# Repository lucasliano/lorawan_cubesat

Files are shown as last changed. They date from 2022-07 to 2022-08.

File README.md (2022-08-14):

<!--
*** To avoid retyping too much info. Do a search and replace for the following:
*** lorawan_cubesat, LoRaWAN Gateway for cubesat mission, project_description
-->

<!-- PROJECT LOGO -->
<br />
<p align="center">
  <a href="https://github.com/lucasliano/lorawan_cubesat">
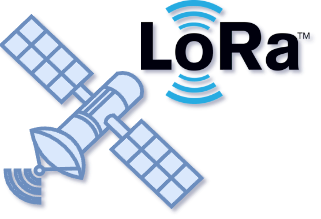
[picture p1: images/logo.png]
    
  </a>

  <h2 align="center">LoRaWAN Gateway:</h3>
  <h3 align="center">Design Criteria for Cubesat Mission</h2>

  <p align="center">
    Cubesat submodule development for a LoRaWAN Gateway capable of operating in harsh environments.
    This project has available not only the design files, but also a report describing the design criteria used. 
    <br />
    <a href="https://github.com/lucasliano/lorawan_cubesat/blob/master/report_spanish.pdf"><strong>Explore the docs »</strong></a>
    <br />
    <br />
    <a href="https://github.com/lucasliano/lorawan_cubesat/tree/master/HW">View Demo</a>
    ·
    <a href="https://github.com/lucasliano/lorawan_cubesat/issues">Report Bug</a>
    ·
    <a href="https://github.com/lucasliano/lorawan_cubesat/issues">Request Feature</a>
  </p>
</p>

<!-- TABLE OF CONTENTS -->
<details open="open">
  <summary><h2 style="display: inline-block">Table of Contents</h2></summary>
  <ol>
    <li><a href="#about-the-project">About The Project</a></li>
    <li><a href="#getting-started">Getting Started</a></li>
    <li><a href="#contributing">Contributing</a></li>
    <li><a href="#license">License</a></li>
    <li><a href="#contact">Contact</a></li>
    <li><a href="#acknowledgements">Acknowledgements</a></li>
  </ol>
</details>

<!-- ABOUT THE PROJECT -->
## About The Project

The project was presented as the final assignament of the subject _Introduction to the design of Printed Circuit Boards_, in the _Electronics Engineering_ carrear at the _Universidad Tecnológica Nacional_ located in Buenos Aires, Argentina.

The main goal of the project was to described the design criteria used in the implementation of the layout, while desiging for manufacturing. As the project was develop in less than 2 month, which you can verify looking at the history of this repo, the scope was modified.

I'm still learning about these topics. If you find something wrong in the design, please let me know. I will be grateful at any feedback received.

In this project you will find the `Altium Designer` project files:

<p align="center">
  <a href="https://github.com/lucasliano/lorawan_cubesat/tree/master/HW">
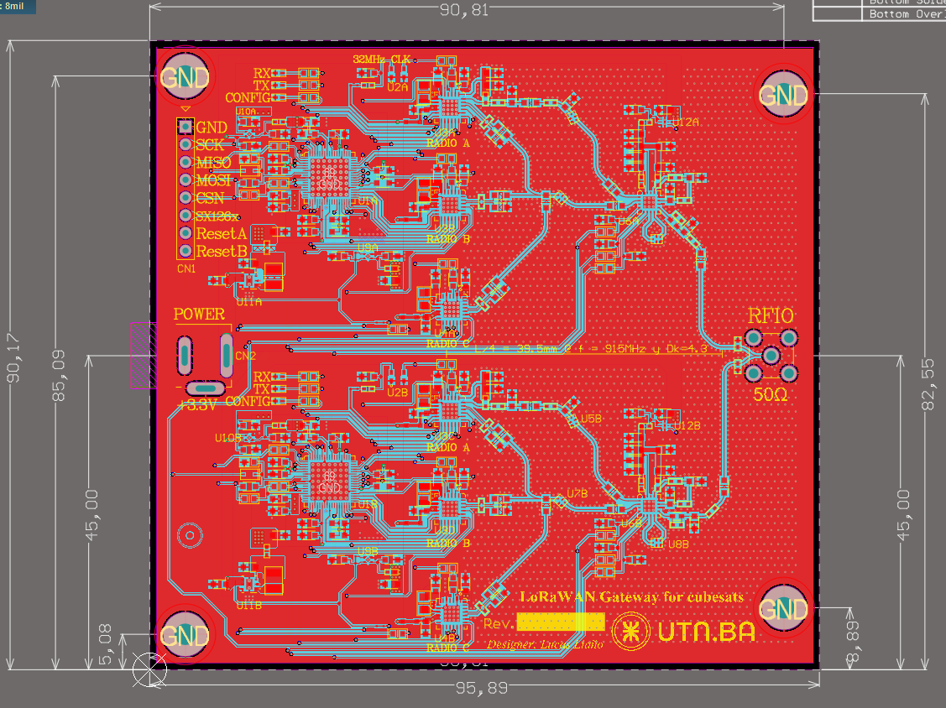
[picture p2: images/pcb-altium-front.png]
  
  </a>
  <p align="center" style="font-size:0.75em;">Figure 1: Altium Designer view for the top leyer of the PCB layout.</p>
</p>

As well as a report containing all the details of the development. Unfortunately, this report is only available in spanish. If you are an english-speaker, please contact me if you have any concerns. 

<p align="center">
  <a href="https://github.com/lucasliano/lorawan_cubesat/blob/master/report_spanish.pdf">
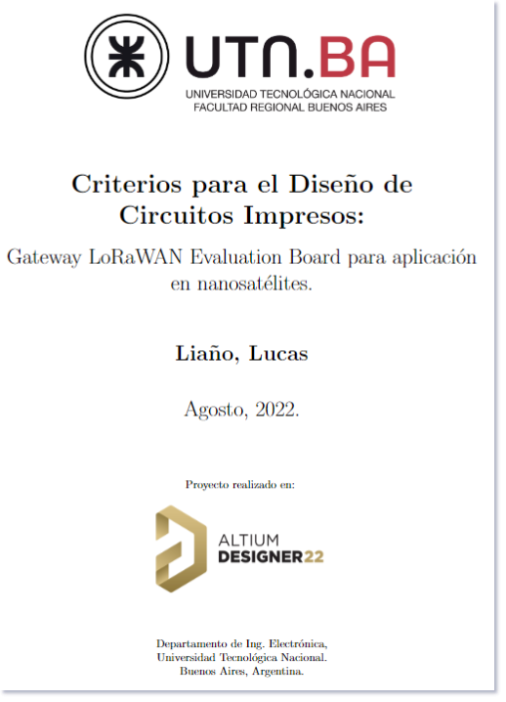
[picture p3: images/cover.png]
  
  </a>
  <p align="center" style="font-size:0.75em;">Figure 2: Report cover.</p>
</p>

<!-- GETTING STARTED -->
## Getting Started

This project was develop using Altium Designer 22. The project folder is '_HW/lorawan_gateway_'.

Cloning the repo will be enough to explore the design files. You will need an Altium Designer license

   ```sh
   git clone https://github.com/lucasliano/lorawan_cubesat.git
   ```

<!-- CONTRIBUTING -->
## Contributing

Contributions are what make the open source community such an amazing place to be learn, inspire, and create. Any contributions you make are **greatly appreciated**.

1. Fork the Project
2. Create your Feature Branch (`git checkout -b feature/AmazingFeature`)
3. Commit your Changes (`git commit -m 'Add some AmazingFeature'`)
4. Push to the Branch (`git push origin feature/AmazingFeature`)
5. Open a Pull Request

See the [open issues](https://github.com/lucasliano/lorawan_cubesat/issues) for a list of proposed features (and known issues).

<!-- LICENSE -->
## License

Distributed under the MIT License. See `LICENSE` for more information.

However, I would appreciate if you tell me in case find this information helpful (or not).

<!-- CONTACT -->
## Contact

[Lucas Liaño](https://www.linkedin.com/in/lucas-lia%C3%B1o/) - lliano@frba.utn.edu.ar

Project Link: [https://github.com/lucasliano/lorawan_cubesat](https://github.com/lucasliano/lorawan_cubesat)

<!-- ACKNOWLEDGEMENTS -->
## Acknowledgements

* [Semtech SX1302 Reference Design files](https://www.semtech.com/products/wireless-rf/lora-core/sx1302cssxxxgw1)

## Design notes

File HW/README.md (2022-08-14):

# This folder contains all the hardware related files.

The following images are a preview of the final PCB, and its panel. 

## Design files

<p align="center">
  
  <p align="center" style="font-size:1em;">Figure 1: Altium Designer view for the top leyer of the PCB layout.</p>
</p>

<p align="center">
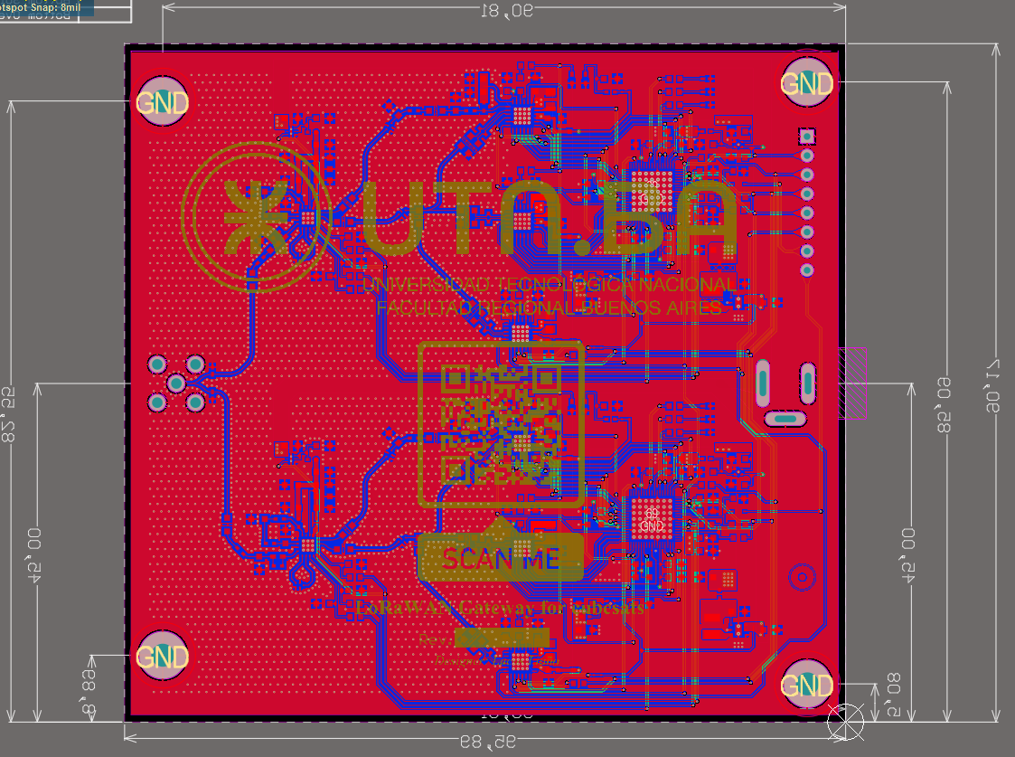
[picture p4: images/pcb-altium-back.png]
  
  <p align="center" style="font-size:1em;">Figure 2: Altium Designer view for the bottom leyer of the PCB layout.</p>
</p>

## 3D Renders

<p align="center">
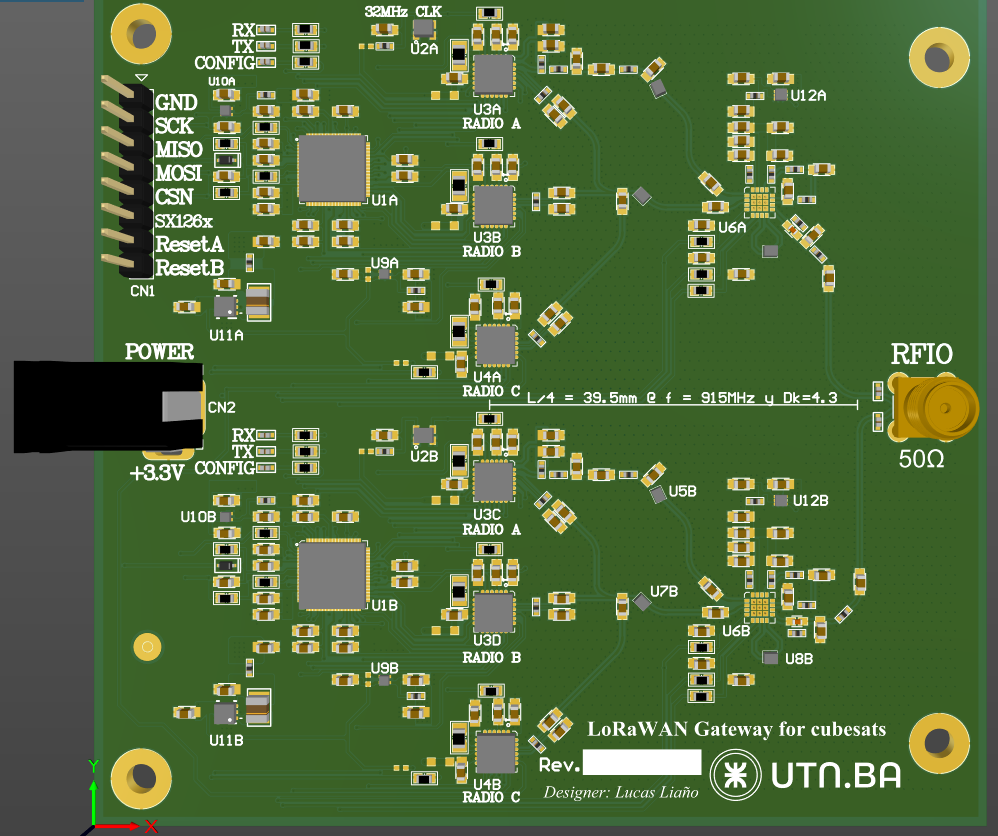
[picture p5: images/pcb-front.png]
  
  <p align="center" style="font-size:1em;">Figure 3: 3D render of the top view.</p>
</p>

<p align="center">
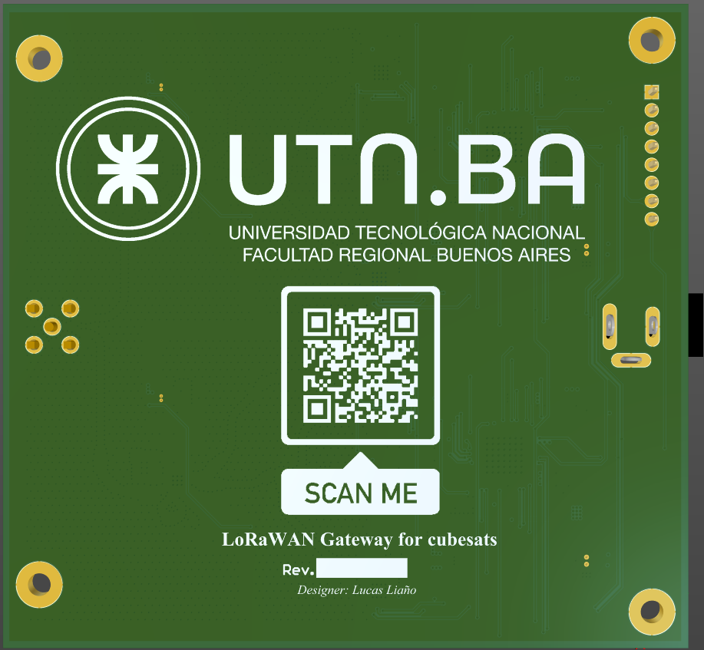
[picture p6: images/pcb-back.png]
  
  <p align="center" style="font-size:1em;">Figure 4: 3D render of the bottom view.</p>
</p>

## Panel 3D render

<p align="center">
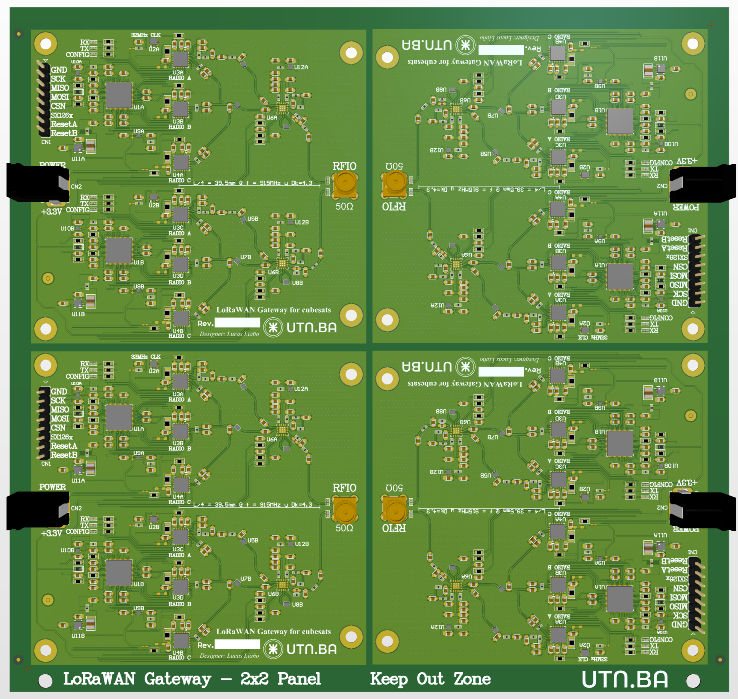
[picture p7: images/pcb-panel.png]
  
  <p align="center" style="font-size:1em;">Figure 5: 3D render of the fianl panel.</p>
</p>

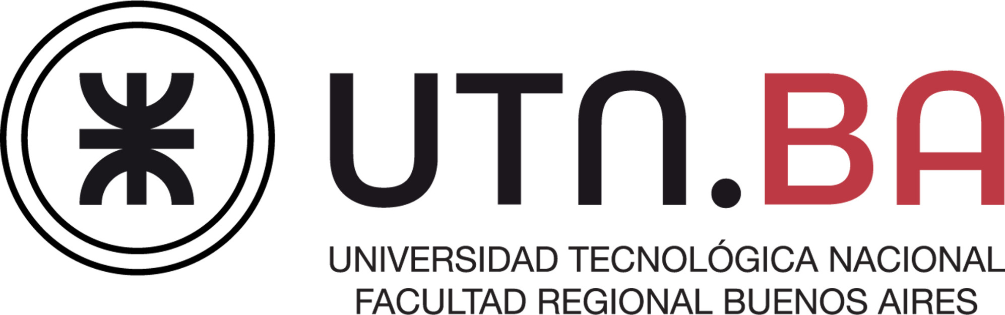
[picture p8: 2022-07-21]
images/utn.jpg

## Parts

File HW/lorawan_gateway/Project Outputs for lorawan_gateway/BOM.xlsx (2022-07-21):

Designator | MPN | Comment | Description | Footprint | Quantity
C1A, C1B, C2A, C2B, C4A, C4B, C5A, C5B, C6A, C6B, C7A, C7B, C9A, C9B, C11A, C11B, C13A, C13B, C26A, C26B, C26C, C26D, C32A, C32B, C50A, C50B, C53A, C53B, C59A, C59B, C60A, C60B | C1206C104K4HACAUTO | 100nF 16V X8R | Capacitor | C_0603 | 32
C3A, C3B, C8A, C8B, C10A, C10B, C12A, C12B, C23A, C23B, C23C, C23D, C29A, C29B | CGA4J3X8R1C105K125AB | 1uF 16V X8R | Capacitor | C_0603 | 14
C14A, C14B | GCM188R91H102KA37D | 100nF 50V X8R | Capacitor | C_0603 | 2
C15A, C15B | GCM188R91H472KA37D | 47nF 50V X8R | Capacitor | C_0603 | 2
C16A, C16B | 0603J0500470GAT | 47pF 50V C0G | Capacitor | C_0603 | 2
C17A, C17B | 06035A390FAT2A | 39pF 50V C0G | Capacitor | C_0603 | 2
C18A, C18B, C38A, C38B | GRM0335C1H100FA01D | 10pF 50V C0G | Capacitor | C_0603 | 4
C19A, C19B | GRM0335C1H2R7WA01D | 2.7pF 50V C0G | Capacitor | C_0603 | 2
C20A, C20B | ML03512R1BAT2A | 2.1pF 50V C0G | Capacitor | C_0603 | 2
C21A, C21B, C21C, C21D, C27A, C27B | C0603X100J8HACAUTO | 10pF 10V X8R | Capacitor | C_0603 | 6
C22A, C22B, C22C, C22D, C24A, C24B, C24C, C24D | GJM0335C1H3R6WB01 | 3.6pF 50V C0G | Capacitor | C_0603 | 8
C25A, C25B, C25C, C25D, C31A, C31B | VJ0603H472JXXAC | 470nF 25V X8R | Capacitor | C_0603 | 6
C28A, C28B, C39A, C39B | GJM0335C1H2R4WB01 | 2.4pF 50V C0G | Capacitor | C_0603 | 4
C30A, C30B, C44A, C44B | GJM0335C1H1R8WB01 | 1.8pF 50V C0G | Capacitor | C_0603 | 4
C33A, C33B, C49A, C49B, C55A, C55B, C57A, C57B | CGA5L3X8R1C475M160AB | 4.7uF 16V X8R | Capacitor | C_0603 | 8
C34A, C34B | C0603C103J3HAC7867 | 10nF 25V X8R | Capacitor | C_0603 | 2
C35A, C35B | C0603C102J1HACAUTO | 1nF 100V X8R | Capacitor | C_0603 | 2
C36A, C36B | GJM1555C1H330GB01 | 33pF 50V C0G | Capacitor | C_0603 | 2
C37A, C37B | GRM1555C2A121GE01 | 120pF 100V C0G | Capacitor | C_0603 | 2
C40A, C40B, C41A, C41B, C43A, C43B, C45A, C45B, C46A, C46B, C47A, C47B | 0603J0500560KCT | 56pF 50V C0G | Capacitor | C_0603 | 12
C42A, C42B | GJM0335C1H2R1BB01 | 2.1pF 50V C0G | Capacitor | C_0402 | 2
C48A, C48B | C2012X7R1A106K125AC | 10uF 10V X7R | Capacitor | C_0603 | 2
C51A, C51B, C52A, C52B, C54A, C54B, C56A, C56B | C0603C105K8RAC7867 | 1uF 10V X7R | Capacitor | C_0603 | 8
C58A, C58B | CGA6P3X8R1C106M250AB | 10uF 16V X8R | Capacitor | C_0603 | 2
CN1 | 2011-1X08G00SB | Generic 1x8 Connector | Connector Generic 8 Vias | Header_M_1x8_0.1" | 1
CN2 | PJ-002B | Barrel Power Connector | CONN PWR JACK 2.5X5.5MM SOLDER | PJ002B | 1
D1A, D1B | BAT54XV2T1G | BAT54XV2T1G | DIODE SCHOTTKY 30V 200MA SOD523 | SOD-523 | 2
D2A, D2B, D3A, D3B, D4A, D4B | APHHS1005SURCK | APHHS1005SURCK | LED | D_0402 | 6
D5A, D5B | LXES15AAA1-153 | LXES15AAA1-153 | LXES Series - ESD Protection Device - Ultra Low Capacitance | D_0402 | 2
F1A, F1B, F2A, F2B, F3A, F3B, F4A, F4B, F5A, F5B | BLM15PG100SN1D | BLM15PG100SN1D | Ferrite bead 10 ohm 1A | L_0402 | 10
J1 | 1053374-1 | SMA RF Connector | SMA 50 Ohm military grade THT connector | SMA THT connector | 1
L1A, L1B | LQW15AN47NJ00D | LQW15AN47NJ00D | Inductor | L_0402 | 2
L2A, L2B | LQW15AN2N5C00D | LQW15AN2N5C00D | Inductor | L_0402 | 2
L3A, L3B | LQW15AN4N7C00 | LQW15AN4N7C00 | Inductor | L_0402 | 2
L4A, L4B, L4C, L4D | LQW15AN12NH00D | 12nH 500mA | Inductor | L_0402 | 4
L5A, L5B, L5C, L5D, L7A, L7B | MLZ2012M150WT000 | 15uH 250mA | FIXED IND 15UH 250MA 950MOHM SMD | 0805[2012] | 6
L6A, L6B | LQW15AN15NH00D | LQW15AN15NH00D | Inductor | L_0402 | 2
L8A, L8B | LQW15AN6N8G80D | 6.8nH 1.45A | Inductor | L_0402 | 2
L9A, L9B | LQG15WZ2N7C02D | 2.7nH 900mA | Inductor | L_0402 | 2
L10A, L10B | LQW15AN7N5J00D | 7.5nH 570mA | Inductor | L_0402 | 2
L11A, L11B | LQP15MN1N2B02 | 1.2nH 390mA | Inductor | L_0402 | 2
L12A, L12B | LQW15AN4N7C00 | 4.7nH 750mA | Inductor | L_0402 | 2
L13A, L13B | LQG15HN3N3S02 | 3.3nH 800mA | Inductor | L_0402 | 2
L14A, L14B | LQM2HPN2R2MJ0L | 2.2uH 1A | FIXED IND 2.2UH 1A 150 MOHM | L_1008 | 2
R1A, R1B, R12A, R12B | RMCF0201JT100R | 100R 5% 1/20W | Resistor | 0603[1608] | 4
R2A, R2B | Vishay | 10R 5% 1/20W | Resistor | 0603[1608] | 2
R3A, R3B, R7A, R7B | M55342K11B47K0MT1V | 47k 5% 1/20W | Resistor | 0603[1608] | 4
R4A, R4B, R5A, R5B, R6A, R6B | ERJ-H3GJ681V | 680R 5% 1/8W | Resistor | 0603[1608] | 6
R10A, R10B, R10C, R10D, R11A, R11B | ERJ-1GNJ221C | 220R 5% 1/20W | Resistor | 0603[1608] | 6
R13A, R13B, R14A, R14B, R15A, R15B | RMCF0201JT1K00 | 1k 5% 1/20W | Resistor | 0603[1608] | 6
U1A, U1B | SX1302 | SX1302IMLTRT | LoRa Core™ Digital Baseband Chip for LoRaWAN network gateways | vqfn68_7x7mm | 2
U2A, U2B | NT2016SA 32MHz END4263A | 32MHz Clipped Sinewave | 32MHz TCXO - Clipped Sinewave Output | TCXO 2.0x1.6mm | 2
U3A, U3B, U3C, U3D | SX1250IMLTRT | SX1250 | SX1250 - Ultra low power RF Front-End | vqfn24_4x4mm | 4
U4A, U4B | SX1261IMLTRT | SX1261/2 | SX1261/2 - Ultra low power RF transceiver | vqfn24_4x4mm | 2
U5A, U5B, U7A, U7B, U8A, U8B | B39921B4344P810 | SAW Filter RF360 | SAW Filter RF360 | QCS5P_1.4x1.1mm | 6
U6A, U6B | SKY66423-11 | SKY66423-11 | SKY66423-11 - 860 to 930MHz Front-End Module | SKY66420_16P_3x3mm | 2
U9A, U9B | NCP114AMX330TBG | LDO 3.3V | LDO IC Positive Fixed 1 Output 300mA 4-UDFN (1.0x1.0) | UDFN4_1x1mm | 2
U10A, U10B | NCP103AMX300TCG | LDO 3V3 | LDO IC Positive Fixed 1 Output 150mA 4-UDFN | UDFN4_1x1mm | 2
U11A, U11B | TPS62242DRVT | Switching Regulator 1.2V | Switching Regulator IC Positive Fixed 1.2V 1 Output 300mA 6-WDFN | WSON-6 | 2
U12A, U12B | NCP176BMX330TCG | LDO 3.3V | LDO IC Positive Fixed 1 Output 500mA 6-XDFN (1.2x1.2) | XDFN6_1.2X1.2mm | 2

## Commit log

2022-06-11 Adding Sch and footprint libs w/ passives and SX1302
    [lorawan_gateway.PrjPcb, main.SchDoc]
2022-06-11 Importing semtech libs + some symbols editing
    [SX1302.SchDoc, main.SchDoc]
2022-06-12 first sch page @ 80%
    [SX1302.SchDoc, lorawan_gateway.PrjPcb]
2022-06-13 SX1302 page 100% done. General Gateway proposal was stated in a new sheet
    [Gateway.SchDoc, SX1302.SchDoc, lorawan_gateway.PrjPcb]
2022-06-14 SX1250 & SX126x were added
    [FrontEnd.SchDoc, Gateway.SchDoc, SX1250.SchDoc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]
2022-06-14 minor change on net
    [Gateway.SchDoc]
2022-06-15 RF FrontEnd was partially added to the SCH
    [FrontEnd.SchDoc, Gateway.SchDoc, SX1250.SchDoc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]
2022-06-21 FrontEnd sch done
    [FrontEnd.SchDoc, Gateway.SchDoc, SX1250.SchDoc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]
2022-06-21 System sheet was added and PC104 symbols too!
    [Gateway.SchDoc, PC104.SchDoc, Power.SchDoc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]
2022-06-23 Connector was changed
    [PC104.SchDoc, PCI104-Express.SchDoc, Power.SchDoc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]
2022-06-24 Schematic complete, but it has errors
    [FrontEnd.SchDoc, Gateway.SchDoc, PCI104-Express.SchDoc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]
2022-06-24 Minor changes
    [SX126x.SchDoc, SX1302.SchDoc]
2022-06-24 No errors, only footprint warnings left!
    [FrontEnd.SchDoc, Gateway.SchDoc, Power.SchDoc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]
2022-06-25 All passive w/ footprint
    [FrontEnd.SchDoc, Gateway.SchDoc, Power.SchDoc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]
2022-06-25 Sch done and PCB was created
    [FrontEnd.SchDoc, Gateway.SchDoc, Power.SchDoc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]
2022-06-26 Layer stack was updated and a SMA step 3D model was added
    [Gateway.SchDoc, System.SchDoc, lorawan_gateway.PrjPcb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]
2022-06-26 SX1302 and SKY done
    [Gateway.SchDoc, SX1250.SchDoc, SX126x.SchDoc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]
2022-06-27 All radio components were palced
    [SX1250.SchDoc, SX126x.SchDoc, pci_104.PcbDoc]
2022-06-27 PCI104 dimensions and holes
    [Gateway.SchDoc, pci_104.PcbDoc]
2022-07-01 Adding PDF and working w/ schm
    [FrontEnd.SchDoc, Gateway.SchDoc, Power.SchDoc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]
2022-07-01 Vias were added next to the SX1302
    [pci_104.PcbDoc]
2022-07-01 Layer stack was updated
    [pci_104.PcbDoc]
2022-07-03 More work arround PCB stackup
    [pci_104.PcbDoc]
2022-07-04 RF indicators were added and microstrip was calculated + rule added
    [FrontEnd.SchDoc, Gateway.SchDoc, Power.SchDoc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]
2022-07-05 QR on bottom silkscreen
    [pci_104.PcbDoc]
2022-07-14 Placement was improved + some digital signals were routed
    [FrontEnd.SchDoc, pci_104.PcbDoc]
2022-07-17 SX1250s were routed (digital signals only)
    [Gateway.SchDoc, Power.SchDoc, SX126x.SchDoc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]
2022-07-17 Digital signals routed @ 90%
    [Gateway.SchDoc, Power.SchDoc, lorawan_gateway.PrjPcb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]
2022-07-20 Starting routing the RF circuits
    [FrontEnd.SchDoc, SX1250.SchDoc, SX126x.SchDoc]
2022-07-21 First version almost done
    [lorawan_gateway.PrjPcb]
2022-07-21 PCB was finished
2022-07-21 All done. Files were sent for corrections
    [BOM.xlsx, FrontEnd.SchDoc, Gateway.SchDoc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]
2022-07-25 minor changes con SCH
    [SX1302.SchDoc]
2022-07-25 minor changes sch
    [SX1302.SchDoc, lorawan_gateway.PrjPcb]
2022-08-01 Panel was added
    [lorawan_gateway.PrjPcb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]
